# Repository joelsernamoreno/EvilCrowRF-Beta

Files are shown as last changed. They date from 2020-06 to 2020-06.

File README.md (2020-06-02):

# EvilCrowRF-Beta
Documentation, gerbers, design and schematic.

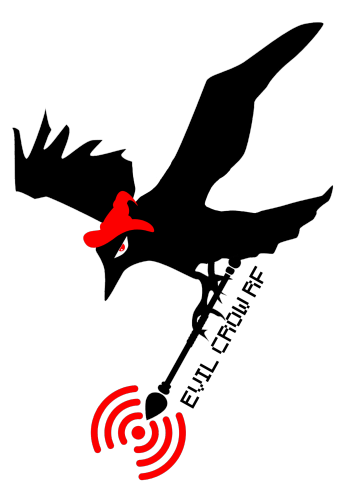
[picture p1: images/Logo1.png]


**Implementation and development:** Joel Serna (@JoelSernaMoreno)

**PCB design:** Ignacio Díaz (@Nacon_96) / Forensic&Security (@ForensicSec)

The developers and collaborators of this project do not earn money with this. 
You can invite me for a coffee to further develop Low-Cost hacking devices. If you don't invite me for a coffee, nothing happens, I will continue developing devices.



# Disclaimer

Evil Crow RF is a basic device for professionals and cybersecurity enthusiasts.

We are not responsible for the incorrect use of Evil Crow RF.

We recommend using this device for testing, learning and fun :D

# Introduction

Evil Crow RF is a radiofrequency hacking device for pentest and Red Team operations, this device operates in the following radiofrequency bands:

* 300Mhz-348Mhz
* 387Mhz-464Mhz
* 779Mhz-928Mhz

Evil Crow RF uses 2 CC1101 modules, these modules can be configured to transmit or receive on different frequencies at the same time.

Evil Crow RF allows the following attacks:

* Signal receiver
* Signal Transmitter
* Replay attacks
* ...

**This device is similar to the device developed by Samy Kamkar (@samykamkar):** https://www.wired.com/2015/08/hackers-tiny-device-unlocks-cars-opens-garages/

In this repository you can find a basic PCB to mount your own Evil Crow RF **(the full version of Evil Crow RF is still under development).**

In this repository you can also find some BASIC sketches for Evil Crow RF. **Sketches for replay or rolljam attacks are not published for ethical reasons.**

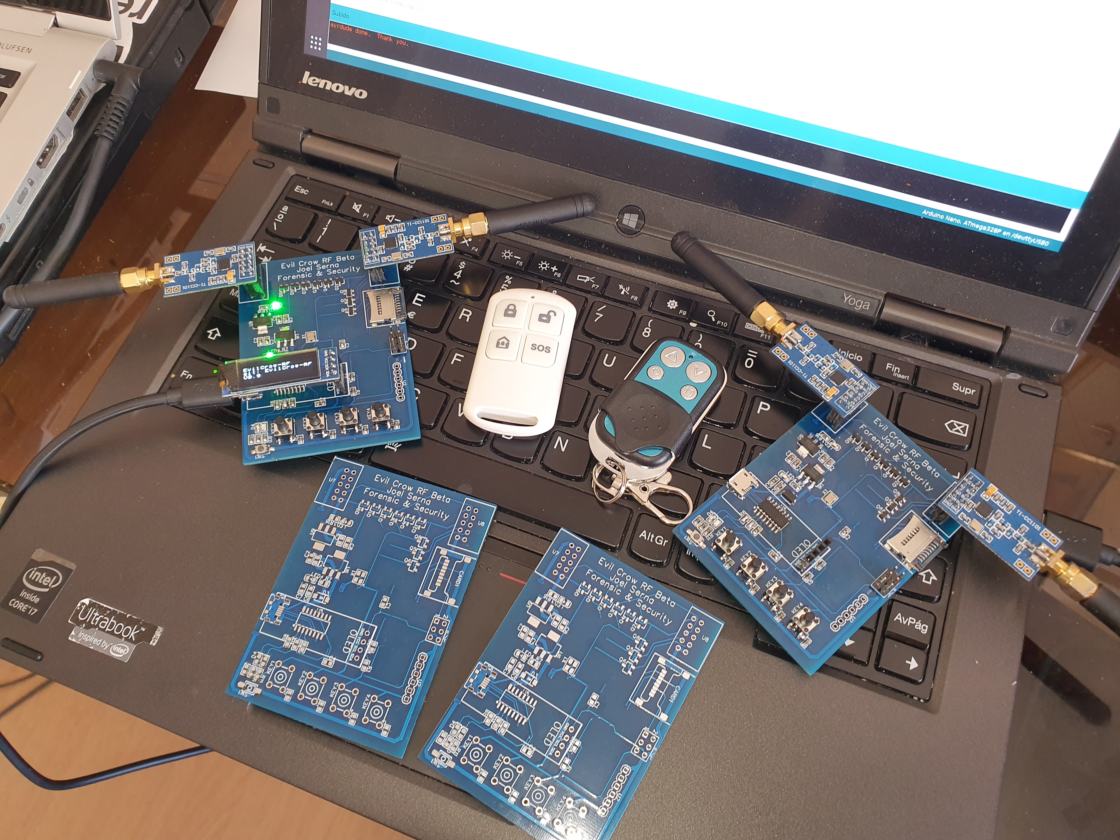
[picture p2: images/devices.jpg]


# Hardware

To mount your own Evil Crow RF you need the following hardware:

* 1x Evil Crow RF PCB

* 2x CC1101 module

* 1x Micro SD

* 1x OLED

# Libraries

Evil Crow RF needs the following libraries:

* https://github.com/LSatan/SmartRC-CC1101-Driver-Lib

* https://github.com/sui77/rc-switch

* https://github.com/davetcc/IoAbstraction

* https://github.com/arduino-libraries/SD

# Installation

1. Download and Install the Arduino IDE: https://www.arduino.cc/en/main/software

2. Download and save the required libraries in the library directory

3. Open any sketch from this repository with the arduino IDE

4. Select Tools - Board - Arduino Nano

5. Select Tools - Processor - Atmega328P

5. Upload sketch and fun!!

# Demo sketch

**oled-example:** Simple skecth to use the oled display.

**EvilCrow_rf_testbuttons** Simple sketch to use the PushButton.

**TXDemo:** Simple sketch to transmit with a CC1101 module.

**RX-315mhz-433mhz:** Sketch to receive with two CC1101 modules at the same time.

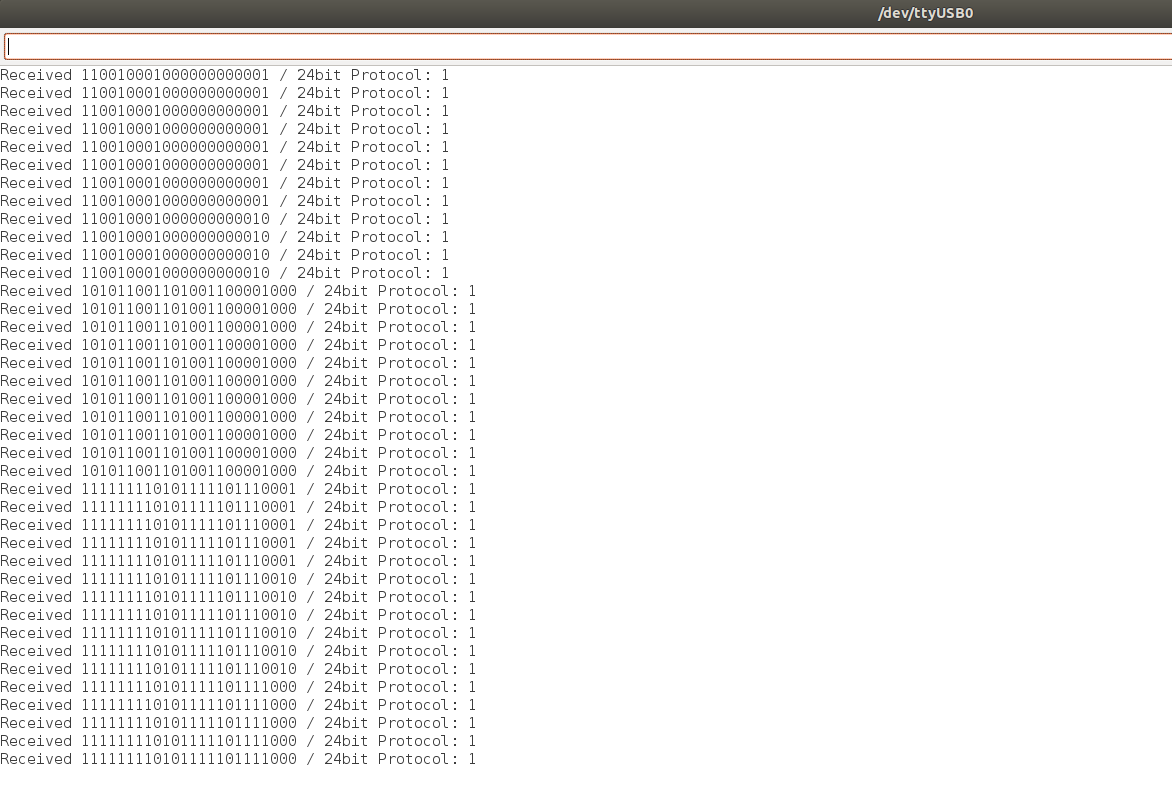
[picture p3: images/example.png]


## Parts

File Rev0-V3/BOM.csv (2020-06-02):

ID | Name | Designator | Footprint | Quantity | Manufacturer Part | Manufacturer | Supplier | Supplier Part | LCSC Assembly
1 | 1k | R11,R10 | R0603 | 2 | ? |  | LCSC | C25585
2 | 100nF | C4,C3,C9,C7,C5,C1 | C0603 | 6 | ? |  | LCSC | C1590
3 | CH340G | U5 | SOIC-16_150MIL | 1 | CH340G | WCH | LCSC | C14267 | Yes
4 | 1k | R16,R9,R7,R8 | R0603 | 4 |  |  | LCSC | C25585
5 | 10uF | C8,C6,C2 | C0603 | 3 | ? |  | LCSC | C1691
6 | SS13 | D3 | SMA(DO-214AC) | 1 | SS13 | MDD | LCSC | C64984
7 | Green LED | D5 | LED 0603 | 1 | ? |  | LCSC | C12624
8 | 3x4x2 | SW1 | KEY-3.0*4.0 | 1 | 3x4x2 | ReliaPro | LCSC | C26638
9 | Red LED | D4 | LED 0603 | 1 | ? |  | LCSC | C2286
10 | NO | P4 | MICRO-USB-4 | 1 | ? |  | LCSC | C40943
11 | HDR2X3 | ICSP | HDR2X3 | 1 | Header-Male-2.54_2x3 | BOOMELE | LCSC | C65114
12 | ATMEGA328_TQFP | U4 | TQFP32 | 1 | ? |  | LCSC | C14877
13 | 10k | R6 | R0603 | 1 | ? |  | LCSC | C25804
14 | CC1101 | U8,U7 | CC1101 | 2
15 | PCF8574T | U1 | SOP-16_L10.3-W7.5-P1.27-LS10.4-BL | 1 | PCF8574T | HGSEMI | LCSC | C398075
16 | TF-102-15 | CARD1 | TF-SMD_TF-102-15 | 1 | TF-102-15 | XUNPU | LCSC | C266609
17 | D-B080508B1-KS2 | LED3,LED4 | LED0805-RD | 2 | D-B080508B1-KS2 | ARKLED | LCSC | C108412
18 | 16MHz | X1 | OSC-SMD_4P-L3.2-W2.5-BL | 1 | M16000E136 | ZheJiang East Crystal Elec | LCSC | C280061
19 | LM1117IMPX-3.3/NOPB | U9 | SOT-223_L6.5-W3.5-P2.30-LS7.0-BR | 1 | LM1117IMPX-3.3/NOPB | TI | LCSC | C23984 | Yes
20 | HEADER-06X1-FEMALE | U2 | 06X1-PTH | 1 | Header-Male-2.54_1x6 | BOOMELE | LCSC | C37208
21 | 10K | R23,R31,R1,R2,R12,R5,R14,R15,R32,R33,R34,R25,R26,R35,R36,R37,R38,R27,R28,R24,R29,R13,R30,R4 | R0603 | 24 | RMC060310K5%N | Tyohm | LCSC | C269684
22 | OLED-0.96-I2C | U3 | OLED | 1
23 | SOLDERJUMPER_2WAYS | SJ2,SJ1,SJ3 | SJ_3 | 3
24 | 12MHz | X2 | OSC-SMD_4P-L3.2-W2.5-BL | 1 | M12000J506 | ZheJiang East Crystal Elec | LCSC | C279583
25 | LM1117IMPX-5.0/NOPB | U6 | SOT-223-3_L6.5-W3.4-P2.30-LS7.0-BR | 1 | LM1117IMPX-5.0/NOPB | TI | LCSC | C41202 | Yes
26 | button6*6*8.5 | KEY1,KEY3,KEY4,KEY2 | KEY-TH_4P-L6.0-W6.0-P4.50 | 4 | button6*6*8.5 | ReliaPro | LCSC | C59980
27 | BSS138_C193019 | Q8,Q7,Q1,Q5,Q4,Q3,Q9,Q2,Q6 | SOT-23-3_L3.0-W1.7-P0.95-LS2.9-BR | 9 | BSS138 | AnBon | LCSC | C193019

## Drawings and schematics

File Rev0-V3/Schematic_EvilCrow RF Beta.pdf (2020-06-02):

## KEYPAD

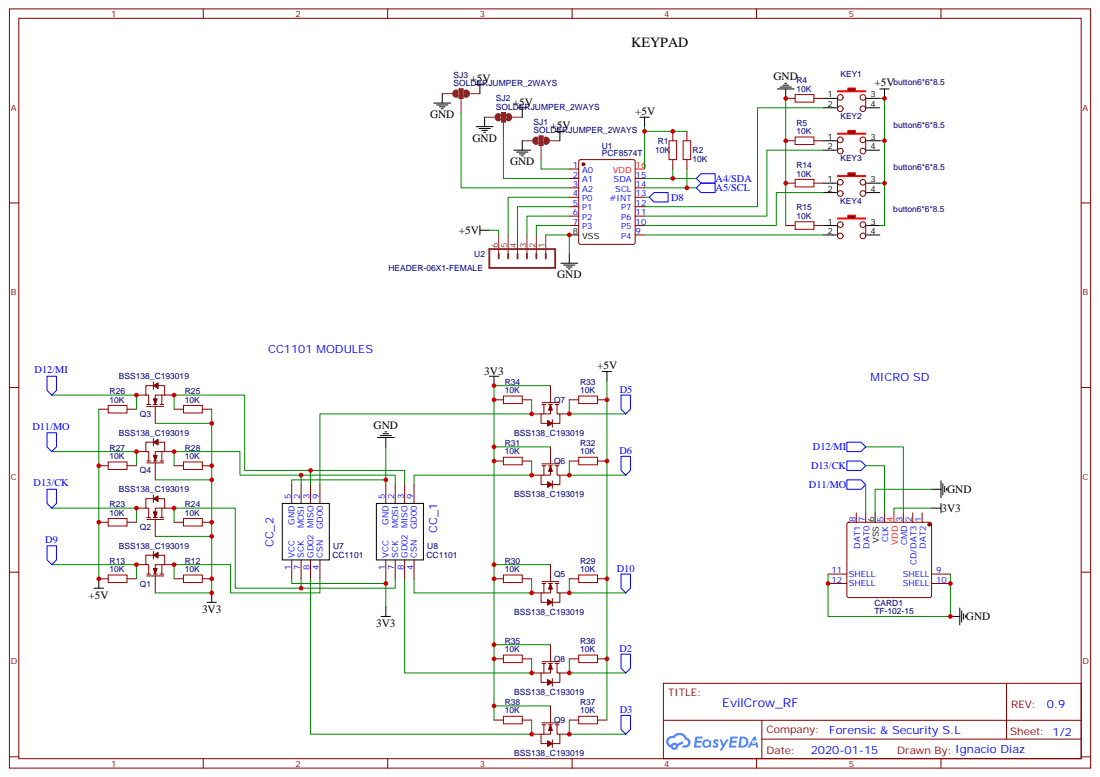
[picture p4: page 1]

P5 10 P6 11 P7 12 #INT 13 SCL 14 SDA 15 VDD 16

## DISPLAY

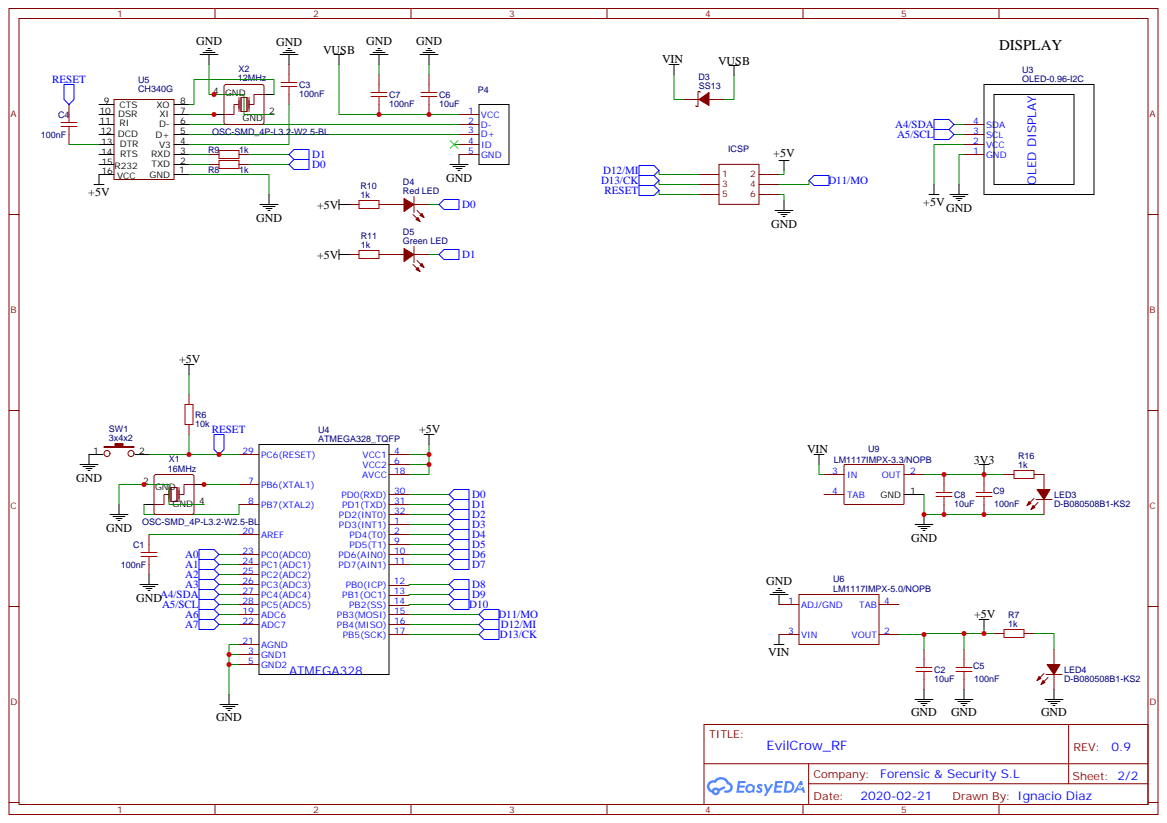
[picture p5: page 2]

Drawn By: Ignacio Diaz

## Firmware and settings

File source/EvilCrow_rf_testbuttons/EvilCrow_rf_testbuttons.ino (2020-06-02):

#include <IoAbstraction.h>
#include <IoAbstractionWire.h>
#include <Wire.h>

IoAbstractionRef ioExpander = ioFrom8574(0x23);

int KeyA = 0;
int KeyB = 0;
int KeyC = 0;
int KeyD = 0;

void setup() {
    Serial.begin(9600);
    Wire.begin();
 
  for (int x=0; x<=7; x++) {
  ioDevicePinMode(ioExpander, x, INPUT);
  }
}

void loop() {
    ioDeviceSync(ioExpander);

    KeyA = ioDeviceDigitalRead(ioExpander, 7);
    KeyB = ioDeviceDigitalRead(ioExpander, 6);
    KeyC = ioDeviceDigitalRead(ioExpander, 5);
    KeyD = ioDeviceDigitalRead(ioExpander, 4);

   if (KeyA == HIGH) {
    Serial.println("KEY A pressed");
   } else {
    Serial.println("No pressed");
   }
}

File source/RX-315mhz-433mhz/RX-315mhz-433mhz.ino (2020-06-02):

#include <RCSwitch.h>
#include <ELECHOUSE_CC1101_RCS_DRV.h>

//CC1101 Pins
int sck = 13;
int miso = 12;
int mosi = 11;
int csn1 = 10;
int csn2 = 9;
int gdo0_1 = 6;
int gdo2_1 = 0;
int gdo0_2 = 5;
int gdo2_2 = 1;

float CC1101_1_Freq = 433.92;
float CC1101_2_Freq = 315.00;

RCSwitch mySwitch = RCSwitch();
RCSwitch CC1101_1 = RCSwitch();
RCSwitch CC1101_2 = RCSwitch();

void setup() {

  Serial.begin(9600);
  
  //setup cc1101
  ELECHOUSE_cc1101.setSpiPin(sck, miso, mosi, csn1);
  ELECHOUSE_cc1101.setMHZ(CC1101_1_Freq);
  ELECHOUSE_cc1101.Init(PA10);
  CC1101_1.enableReceive(gdo2_1);
  ELECHOUSE_cc1101.SetRx();

  ELECHOUSE_cc1101.setSpiPin(sck, miso, mosi, csn2);
  ELECHOUSE_cc1101.setMHZ(CC1101_2_Freq);
  ELECHOUSE_cc1101.Init(PA10);
  CC1101_2.enableReceive(gdo2_2);
  ELECHOUSE_cc1101.SetRx();
}

void loop() {
 
  if (mySwitch.available()) {
    
    Serial.print("Received ");
    unsigned long code = mySwitch.getReceivedValue();
    Serial.print( code, BIN);
    Serial.print(" / ");
    Serial.print( mySwitch.getReceivedBitlength() );
    Serial.print("bit ");
    Serial.print("Protocol: ");
    Serial.println( mySwitch.getReceivedProtocol() );

    mySwitch.resetAvailable();

  }
}
